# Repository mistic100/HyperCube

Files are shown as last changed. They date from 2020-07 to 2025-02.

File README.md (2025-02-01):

# HyperCube

Homemade clone of the [HyperCube by the Hyperspace Lighting Company](https://www.hyperspacelight.com/the-hypercube). 23cm wide.

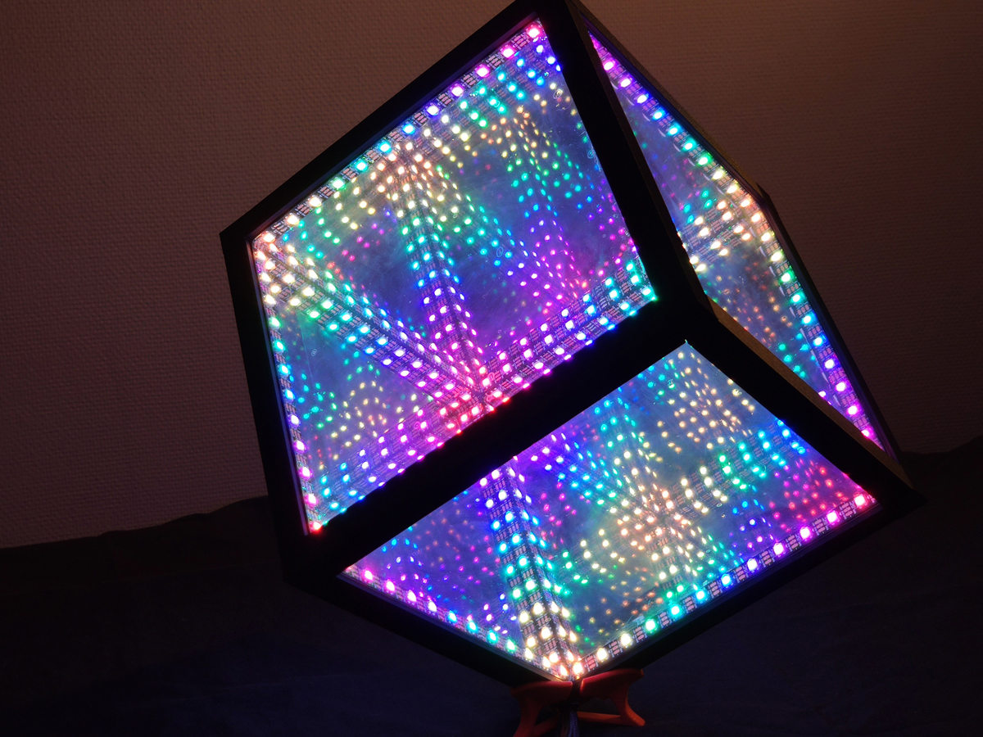
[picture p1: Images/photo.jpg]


[Photos on my website](https://galerie.strangeplanet.fr/index.php?/category/199)

## Parts list

### 3D printed parts

- 6x beam
- 2x beam-w-hole
- 2x beam-bottom (one symmetry !)
- 2x beam-bottom-w-hole (one symmetry !)
- 4x corner
- 4x corner-bottom
- 5x corner-cache
- 1x corner-cache-w-hole
- 4x panel-holder
- 1x electronics-case-support
	- use the alt version if you don't want to include a push-button

### Hardware

- 6x 210mm/2mm square one-way mirrors (or standard glass/PMAA with one-way film)
- 24x M2 15mm conical screws

### Electronics

- 6x 80cm WS2812 LED strips (60 LEDS/m)
- 1x Wemos D1 mini
- 1x 16mm push button
- 1x female DC jack with terminals
- 1x 5-10A 5V power supply

## Assembly

1. Start building the cube from the top panel, taking care where you use beams with or without holes to pass the wires. You will use all beams and corner pieces and five panels, dont put the last bottom panel yet
2. Cut the LED strips to length en solder the wires, I recommend using dedicated power lines for each strip but you can use a single wire for the data line
3. Glue the strips to each side and pass the wires in the beams, all wires must output on the same corner. I recommend adding CA glue as the standard 3M tape is not adhesive enough
4. Check that every strip is working correctly
5. Put the bottom panel and secure it in place by glueing the four panel holders
6. Glue all height corner caches

The following diagram shows one way to arrange strips (flattened cube seen from top).  
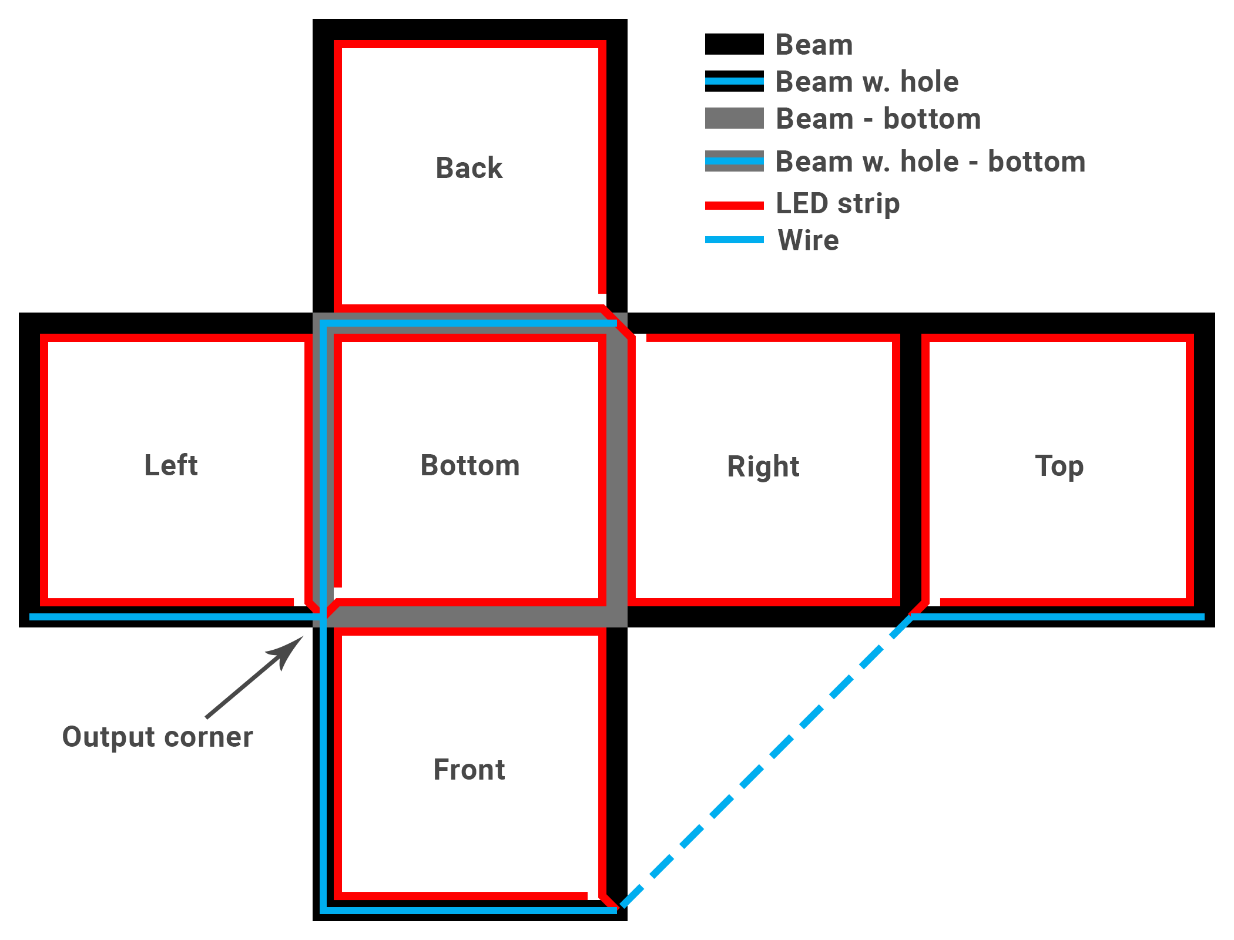
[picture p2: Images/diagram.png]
diagram


## Software

I recommend to install [WLED](https://kno.wled.ge/). Don't forget to divide the maximum power output by 6 as all the strips are in parallel.

However you can find in this repository a custom firmware I don't use anymore alongside a custom Android app. This was developped for an Arduino Nano with a Bluetooth module.

<details>
	<summary>Custom firmware and app</summary>

### Code

#### Configuration

Edit the `constants.h` file according to your wiring :

- `LED_PIN` output pin use to control LEDS
- `BUTTON_PIN` input pin for the control button
- `BLE_RXD` RX pin for the BLE module
- `BLE_TXD` TX pin for the BLE module

Edit `MAX_MILLI_AMPS` according to the rating of your power supply (keep a safety margin, especially with cheap Chinese stuff).

#### Controls

The cube is controlled via USB and Bluetooth and can received basic serial commands (`\n` terminated):

- `ON` to turn on the light
- `OFF` to turn off the light
- `BRIGHT X`(X=0-255) to change the brightness
- `BRIGHT+` to increase the brightness by 16
- `BRIGHT-` to decrease the brightness by 16
- `MODE X` to change the current mode, modes are:
	- `RAINBOW`
	- `RAINDROP`
	- `PULSE`
	- `CYLON`
	- `CHASER`
	- `NOISE`
	- `GRADIENT`
	- `RIPPLES`
- `MODE+` to use the next mode
- `MODE-` to use the previous mode
- `COLOR X` to change the current color, hues are:
	- `RAINBOW`
	- `RED`
	- `YELLOW`
	- `GREEN`
	- `BLUE`
	- `PINK`
	- `WHITE`
- `COLOR+` to use the next color
- `COLOR-` to use the previous color
- `SPEED X` (X=1-10) to change the speed
- `SPEED+` to increase the speed by 1
- `SPEED-` to decrease the speed by 1
- `PATTERN [A=X] [Z=X] C=X` use a custom color pattern
	- `A=X` (X=0/F/B): animate the pattern on `F`orward or `B`ackward direction (uses current `SPEED`)
	- `Z=X` (X=1-10): display the full pattern all at once or only a smaller portion
	- `C=X`: definition of up to 16 color stops, three character each, from `000` to `FFF`
	
*Note*: When controlled over Bluetooth, the controller must send a single `#` char and wait for the `OK` response before sending the command.
This is done to pause the FastLED processing and have enough CPU cycles to consume the larger request.

#### Examples of custom color pattern

- `C=f00`: All red
- `A=F C=000FFF`: Animated Black/White gradient
- `C=000FFF000FFF000FFF000FFF000FFF`: Static checker
- `A=B Z=5 C=F0000F`: Animated Red/Blue gradient with zoom applied
- `A=F Z=10 C=5F55F500000055F000`: Pulsating Green/Blue

*Note*: Commands over 20 chars long must be splitted into multiple packets, by limitation of the Serial over Bluetooth protocol.
Only the last packet will be `\n` terminated.

### Application

A flutter application (Android only) allows to control the light from your smartphone. It is only compatible with HM-10 Bluetooth modules.

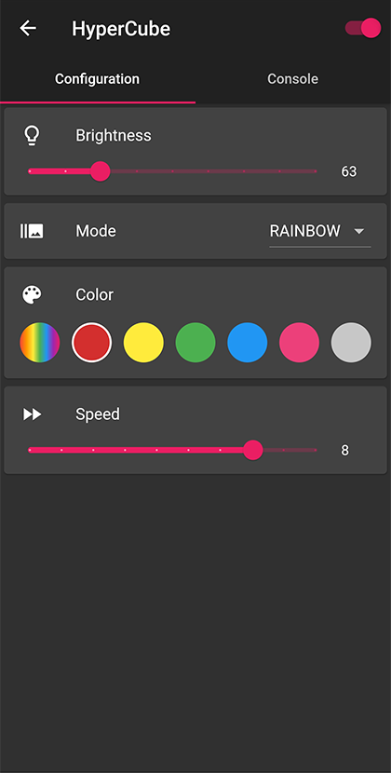
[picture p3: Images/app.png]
app
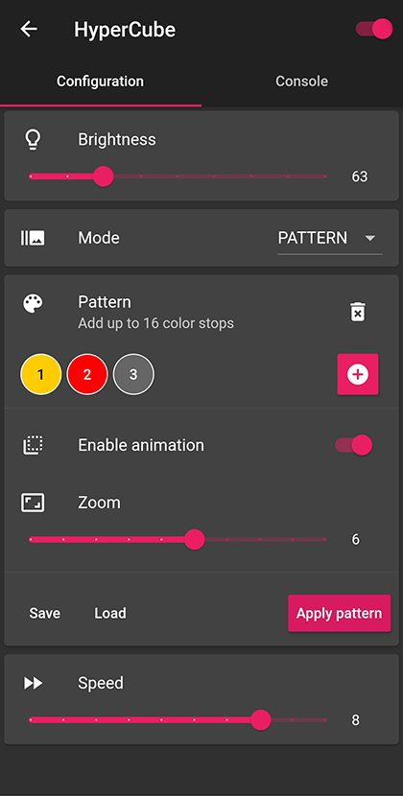
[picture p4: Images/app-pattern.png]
app-pattern
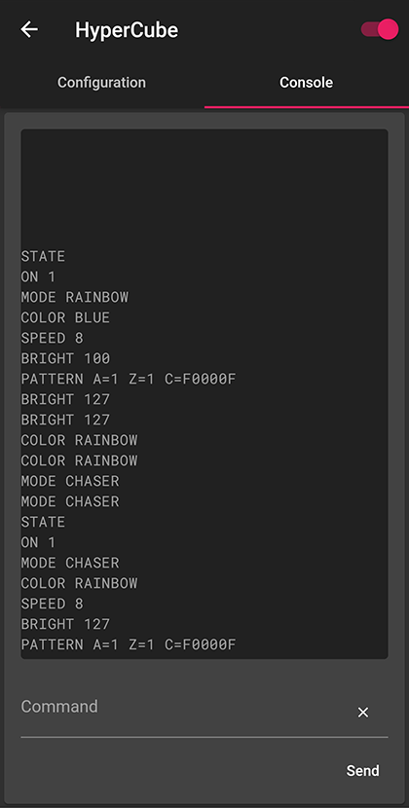
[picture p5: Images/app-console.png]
app-console
  

</details>

## License

The SolidWorks files, Arduino code and Flutter code are distributed under the Creative Commons 3.0 BY-SA license.

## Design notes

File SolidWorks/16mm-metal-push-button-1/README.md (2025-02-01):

https://grabcad.com/library/16mm-metal-push-button-1

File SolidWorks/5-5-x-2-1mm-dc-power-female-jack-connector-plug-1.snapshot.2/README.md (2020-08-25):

https://grabcad.com/library/5-5-x-2-1mm-dc-power-female-jack-connector-plug-1

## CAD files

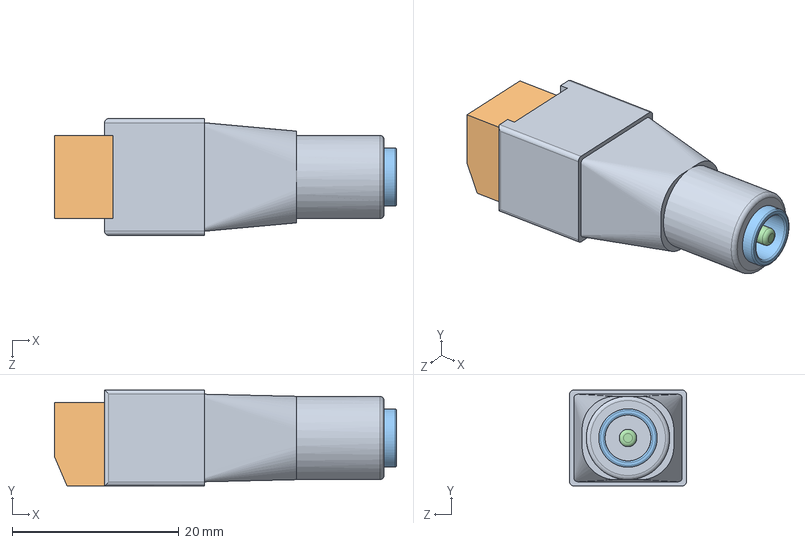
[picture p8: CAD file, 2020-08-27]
SolidWorks/5-5-x-2-1mm-dc-power-female-jack-connector-plug-1.snapshot.2/dc_power_jack_assembly.SLDASM
41.0 x 11.5 x 14.0 mm
main_body
green_screw_section
jack_outer_metal
jack_inner_rod
wireholder x 2

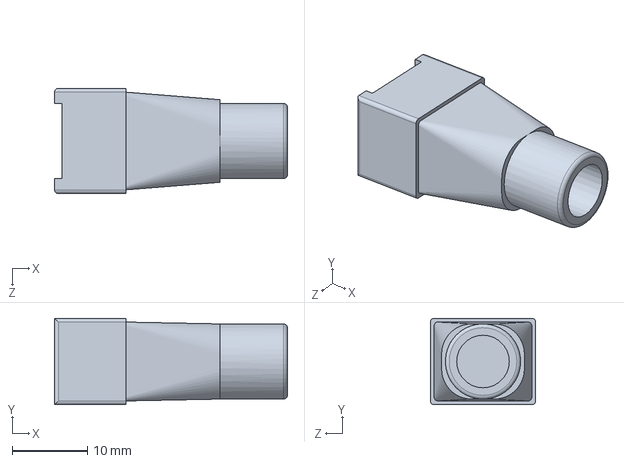
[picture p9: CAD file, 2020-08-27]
SolidWorks/5-5-x-2-1mm-dc-power-female-jack-connector-plug-1.snapshot.2/main_body.SLDPRT
31.0 x 11.5 x 14.0 mm

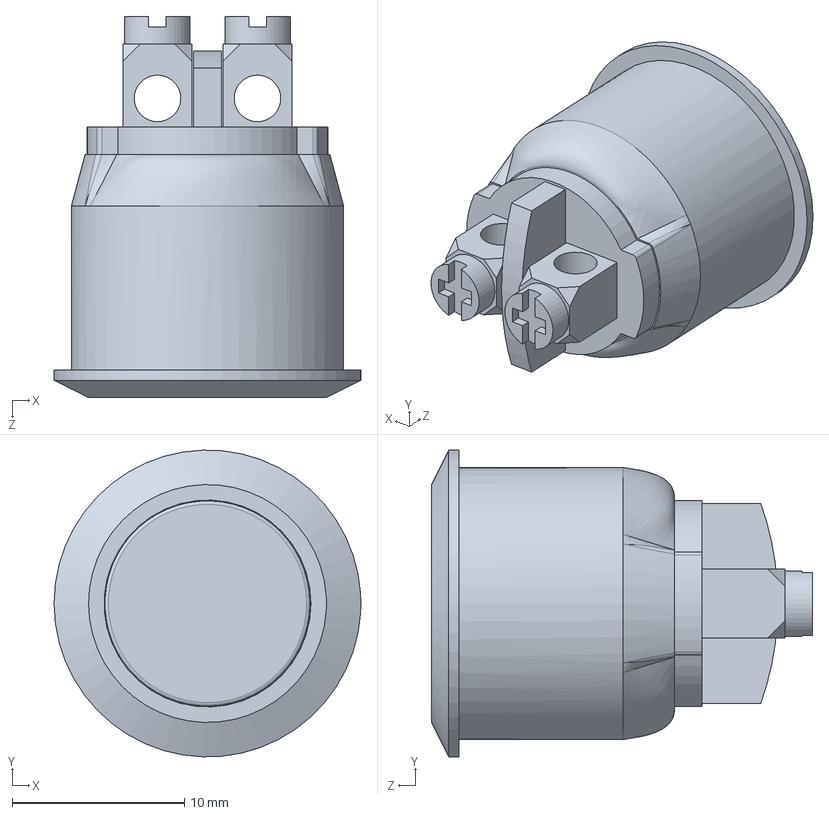
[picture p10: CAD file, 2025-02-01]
SolidWorks/16mm-metal-push-button-1/button.SLDPRT
17.8 x 17.8 x 22.1 mm

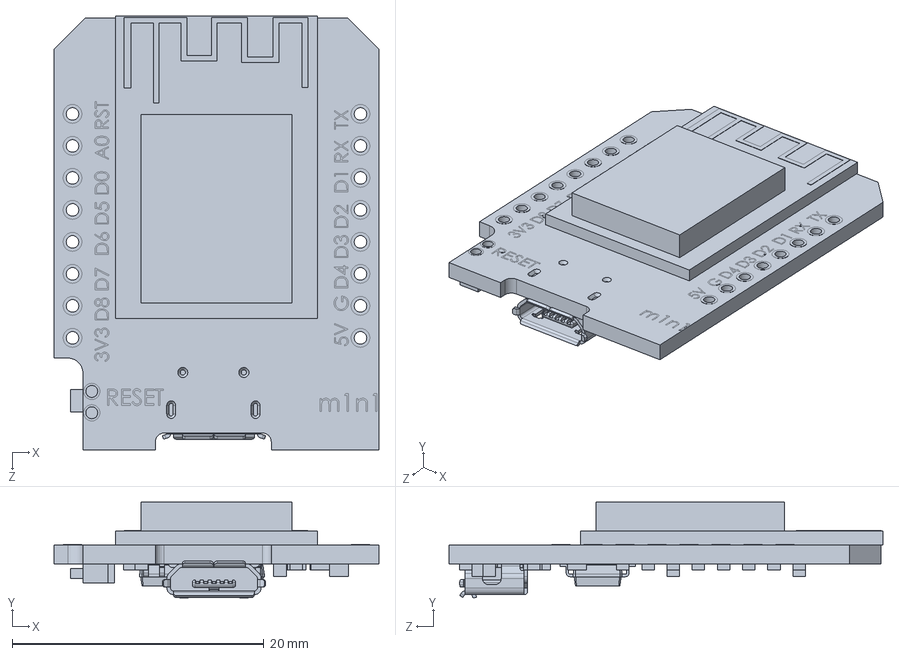
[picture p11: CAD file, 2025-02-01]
SolidWorks/wemos-d1-mini-more-accurate-version-1.snapshot.3/WEMOS-D1-mini_detailed.SLDPRT
25.8 x 7.60 x 34.4 mm

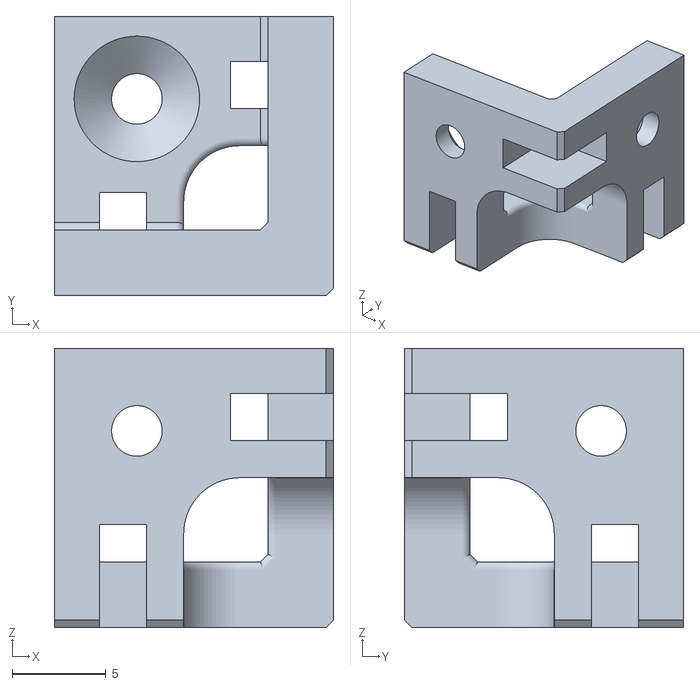
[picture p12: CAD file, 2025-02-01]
STL/corner (x4).STL
14.9 x 14.9 x 14.9

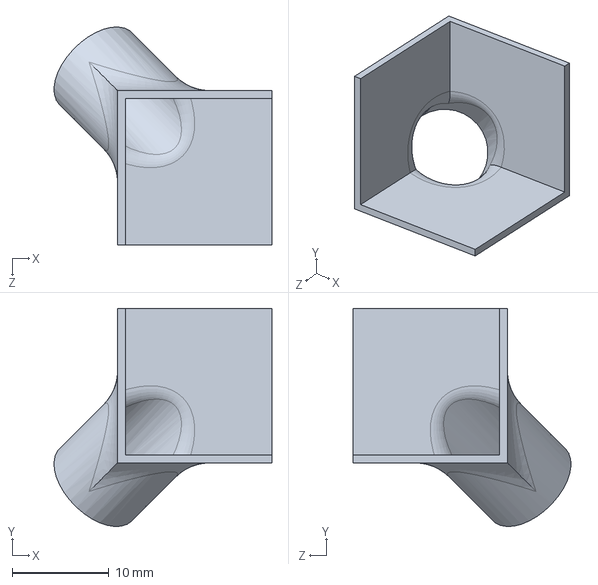
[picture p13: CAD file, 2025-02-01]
SolidWorks/corner-cache-w-hole.SLDPRT
22.6 x 22.6 x 22.6 mm

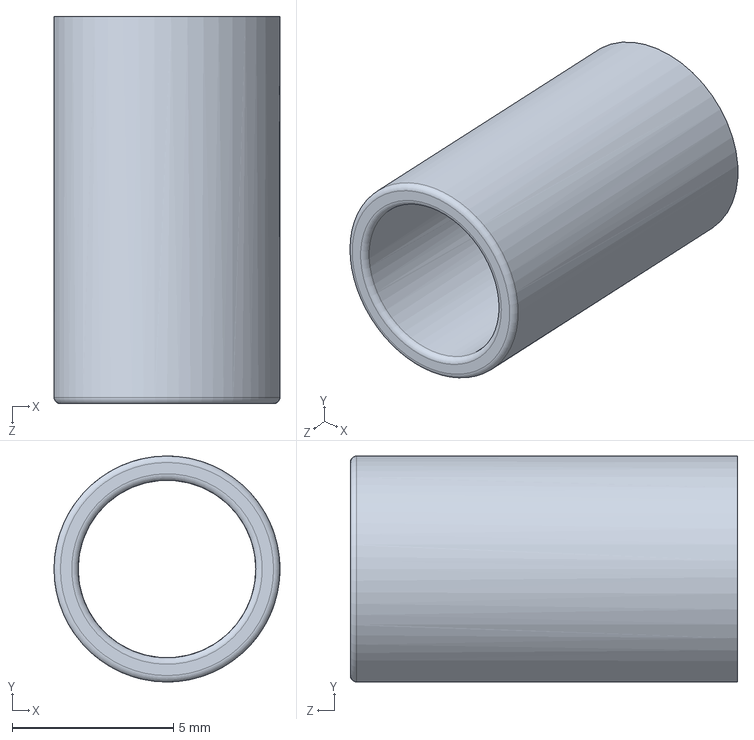
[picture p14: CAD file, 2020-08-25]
SolidWorks/5-5-x-2-1mm-dc-power-female-jack-connector-plug-1.snapshot.2/jack_outer_metal.SLDPRT
7.00 x 7.00 x 12.0 mm

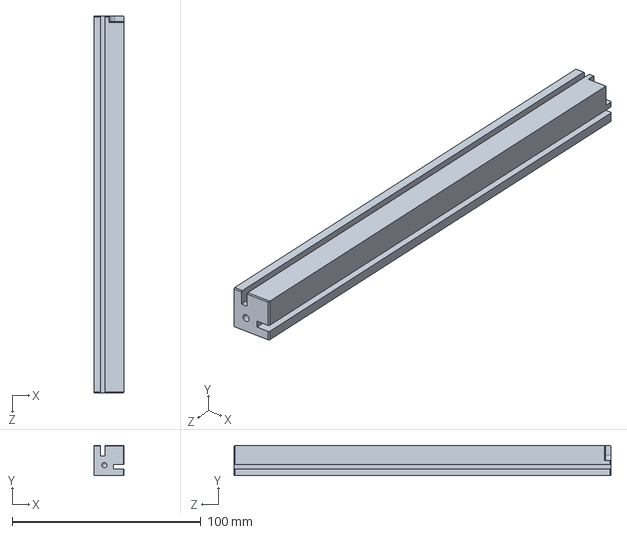
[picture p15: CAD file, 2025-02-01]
SolidWorks/beam.SLDPRT
16.0 x 16.0 x 200.0 mm

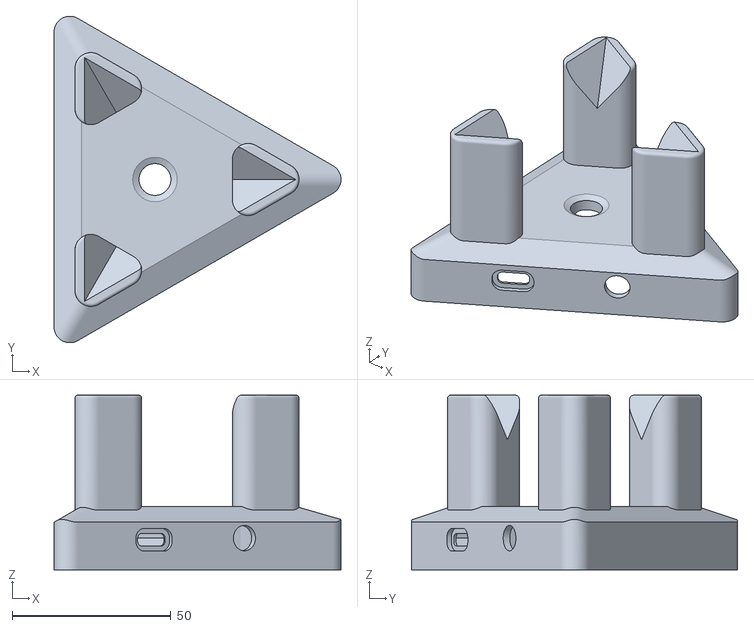
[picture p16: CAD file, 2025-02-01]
STL/electronics-case-support (alt) (x1).stl
90.3 x 102.7 x 55.0

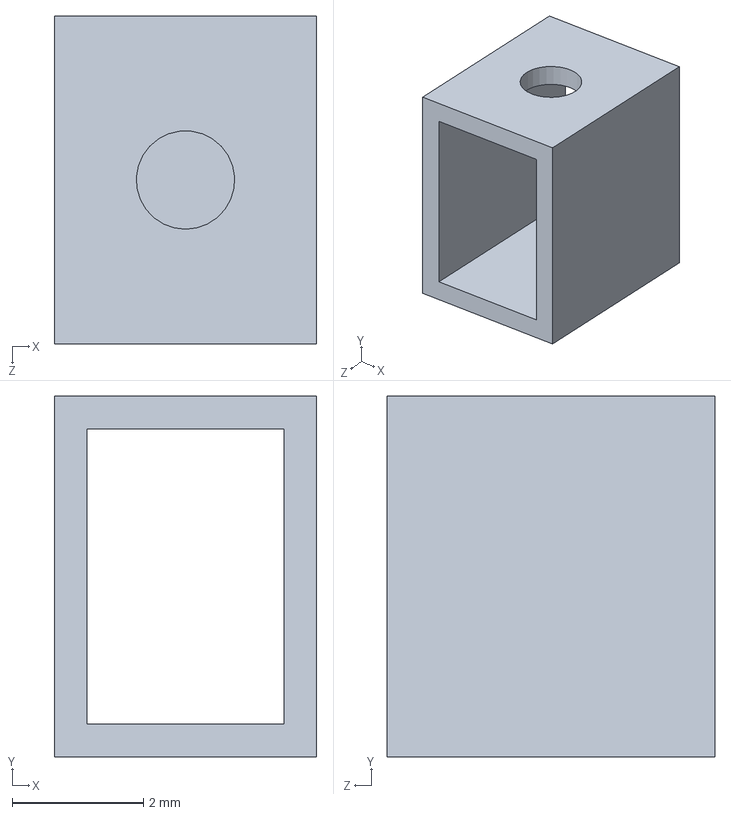
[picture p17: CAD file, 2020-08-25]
SolidWorks/5-5-x-2-1mm-dc-power-female-jack-connector-plug-1.snapshot.2/wireholder.SLDPRT
4.00 x 5.50 x 5.00 mm

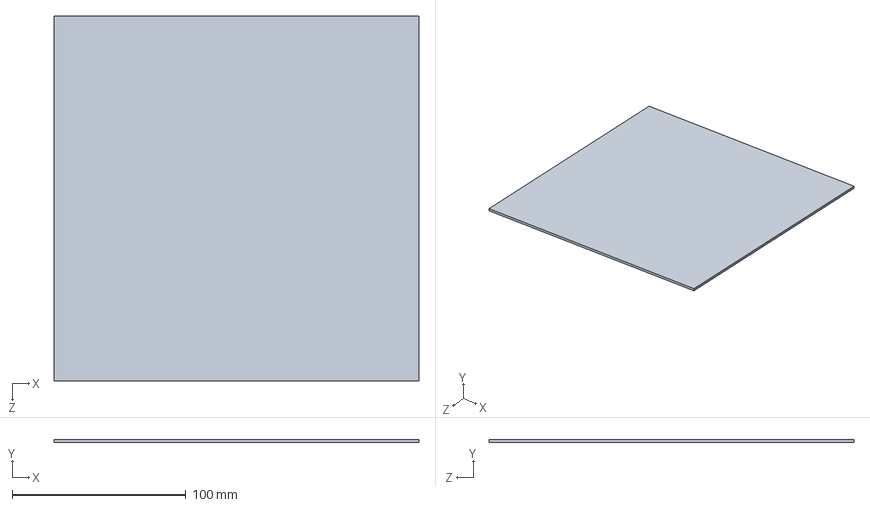
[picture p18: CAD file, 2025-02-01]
SolidWorks/glass.SLDPRT
210.0 x 2.00 x 210.0 mm

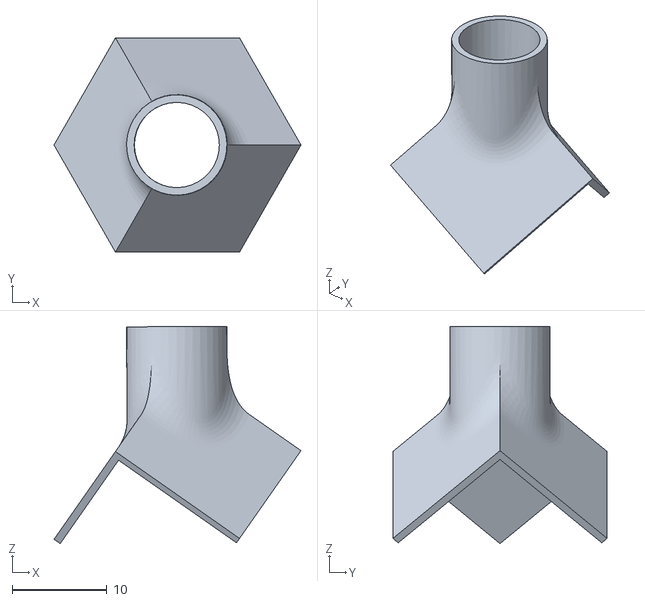
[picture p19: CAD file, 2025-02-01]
STL/corner-cache-w-hole (x1).STL
26.1 x 22.6 x 22.9

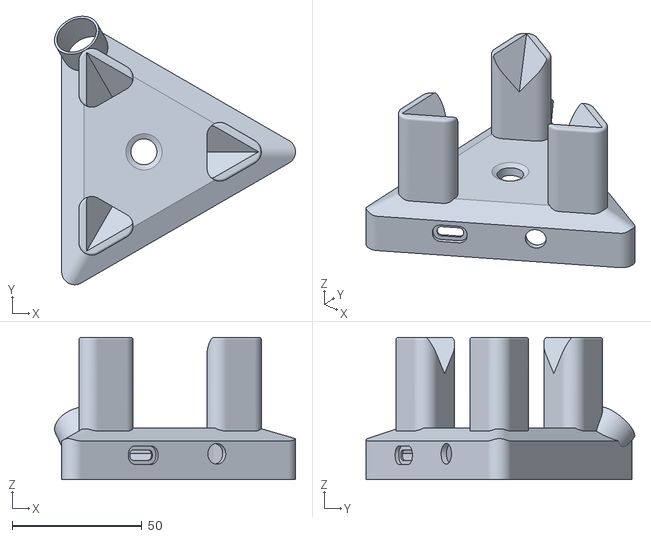
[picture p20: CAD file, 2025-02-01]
STL/electronics-case-support (x1).STL
93.0 x 103.7 x 55.0

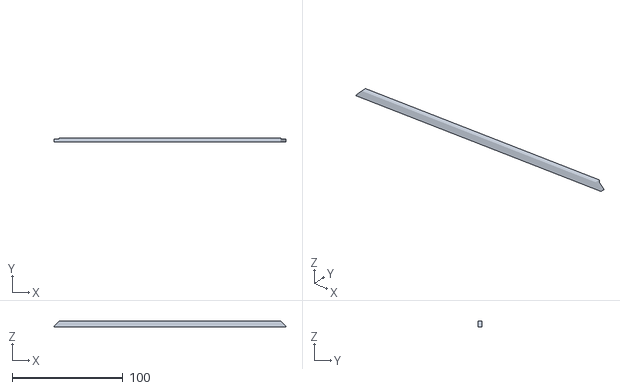
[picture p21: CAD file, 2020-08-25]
STL/panel-holder (x4).STL
209.1 x 4.00 x 5.50

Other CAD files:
SolidWorks/HyperCubeAndCase.SLDASM
SolidWorks/HyperCube.SLDASM
STL/corner-bottom (x4).STL
SolidWorks/electronics-case-support.SLDPRT
STL/beam (x6).STL
STL/beam-bottom (x1 + 1 symmetry).STL
STL/beam-bottom-w-hole (x1 + 1 symmetry).STL
STL/beam-w-hole (x2).STL
STL/corner-cache (x5).STL
SolidWorks/5-5-x-2-1mm-dc-power-female-jack-connector-plug-1.snapshot.2/green_screw_section.SLDPRT
SolidWorks/5-5-x-2-1mm-dc-power-female-jack-connector-plug-1.snapshot.2/jack_inner_rod.SLDPRT
SolidWorks/5-5-x-2-1mm-dc-power-female-jack-connector-plug-1.snapshot.2/wireholder_with_screw_assembly.SLDASM
SolidWorks/beam-base.SLDPRT
SolidWorks/beam-bottom-w-hole.SLDPRT
SolidWorks/beam-bottom-w-hole_symetry.SLDPRT
SolidWorks/beam-bottom.SLDPRT
SolidWorks/beam-bottom_symetry.SLDPRT
SolidWorks/beam-w-hole.SLDPRT
SolidWorks/corner-bottom.SLDPRT
SolidWorks/corner-cache.SLDPRT
SolidWorks/corner.SLDPRT
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

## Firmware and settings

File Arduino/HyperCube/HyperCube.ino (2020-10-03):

#include <FastLED.h>
#include <SoftwareSerial.h>
#include <CmdParser.hpp>
#include <AverageValue.h>
#include <EEPROM.h>
#include "constants.h"
#include "modes.h"
#include "colors.h"
#include "custom.h"
#include "Animations.h"

// animation manager
Animations *animations;

// Bluetooth serial
SoftwareSerial btSerial(BLE_RXD, BLE_TXD);

// Command parser
CmdParser cmdParser;
CmdBuffer<CMD_BUFFER_SIZE> cmdBuffer;

// pause LED processing
boolean pause = false;

// track if the EEPROM needs to be update
boolean needsSave = false;

// touch button value
AverageValue<long> buttonValue(40);
boolean buttonOff = false;

void setup() {
  pinMode(LED_BUILTIN, OUTPUT);
  
  animations = new Animations();

  uint8_t brightness = EEPROM.read(ADDR_BRIGHT);
  if (brightness == 0) {
    brightness = BRIGHTNESS_BASE;
  }
  uint8_t mode = EEPROM.read(ADDR_MODE);
  uint8_t color = EEPROM.read(ADDR_COLOR);
  uint8_t speed = EEPROM.read(ADDR_SPEED);
  if (speed == 0) {
    speed = SPEED_BASE;
  }

  if (EEPROM.read(ADDR_PATTERN) == CUSTOM_PATTERN_VERSION) {
    EEPROM.get(ADDR_PATTERN, animations->pattern);
  }

  animations->setBrightness(brightness);
  animations->setColor(Colors(color % NUM_COLORS));
  animations->setSpeed(speed);
  animations->setMode(Modes(mode == M_PATTERN ? mode : mode % NUM_MODES));

  Serial.begin(9600);
  btSerial.begin(BLE_BAUD);

  FastLED.addLeds<LED_TYPE, LED_PIN, COLOR_ORDER>(animations->leds, NUM_LEDS).setCorrection(TypicalLEDStrip);
  FastLED.setMaxPowerInVoltsAndMilliamps(5, MAX_MILLI_AMPS);
}

void loop() {
  if (!pause) {
    if (btSerial.available() && btSerial.read() == BLE_CTRL_CHAR) {
      // force empty the serial buffer
      delay(100);
      while (btSerial.available()) btSerial.read();
      
      pause = true;
      cmdBuffer.clear();
      btSerial.println(F("OK"));
    } else {
      processCommand(&Serial);
    }
  } else {
    if (processCommand(&btSerial)) {
      pause = false;
    }
  }
  
  EVERY_N_MILLIS_I(timer, 10) {
    buttonValue.push(analogRead(BUTTON_PIN));
    boolean newButtonOff = buttonValue.average() <= BUTTON_THRES;
    if (newButtonOff != buttonOff) {
      buttonOff = newButtonOff;
      if (buttonOff) {
        animations->off();
      } else {
        animations->on();
      }
    }

    if (!pause) {
      timer.setPeriod(animations->period);
      animations->run();
    
      FastLED.setBrightness(animations->brightness);
      FastLED.show();
    
      digitalWrite(LED_BUILTIN, animations->isOff ? LOW : HIGH);
    }
  }

  EVERY_N_SECONDS(5) {
    if (!pause) {
      printOn(&btSerial);
    }
    
    if (needsSave) {
      EEPROM.update(ADDR_BRIGHT, animations->brightness);
      EEPROM.update(ADDR_MODE, animations->mode);
      EEPROM.update(ADDR_COLOR, animations->color);
      EEPROM.update(ADDR_SPEED, animations->speed);
      EEPROM.put(ADDR_PATTERN, animations->pattern);
      needsSave = false;
    }
  }
}

boolean processCommand(Stream* serial) {
  // don't use CmdBuffer#readFromSerial which expects to receive the whole command at once
  bool done = false;
  while (serial->available()) {
      if (cmdBuffer.readSerialChar(serial)) {
          done = true;
          break;
      }
  }

  if (done) {
    cmdParser.setOptKeyValue(true);
    
    if (cmdParser.parseCmd(cmdBuffer.getBuffer(), cmdBuffer.getBufferSize()) != CMDPARSER_ERROR) {
      if (cmdParser.equalCommand_P(PSTR("ON"))) {
        animations->on();
        printOn(serial);
      }
      else if (cmdParser.equalCommand_P(PSTR("OFF"))) {
        animations->off();
        printOn(serial);
      }
      else if (cmdParser.equalCommand_P(PSTR("BRIGHT"))) {
        animations->setBrightness(atoi(cmdParser.getCmdParam(1)));
        needsSave = true;
        printBright(serial);
      }
      else if (cmdParser.equalCommand_P(PSTR("BRIGHT+"))) {
       animations->setBrightness(qadd8(animations->brightness, BRIGHTNESS_STEP));
        needsSave = true;
        printBright(serial);
      }
      else if (cmdParser.equalCommand_P(PSTR("BRIGHT-"))) {
        animations->setBrightness(qsub8(animations->brightness, BRIGHTNESS_STEP));
        needsSave = true;
        printBright(serial);
      }
      else if (cmdParser.equalCommand_P(PSTR("MODE"))) {
        animations->setMode(getMode(cmdParser.getCmdParam(1)));
        needsSave = true;
        printMode(serial);
      }
      else if (cmdParser.equalCommand_P(PSTR("MODE+"))) {
        animations->setMode(Modes((animations->mode + 1) % NUM_MODES));
        needsSave = true;
        printMode(serial);
      }
      else if (cmdParser.equalCommand_P(PSTR("MODE-"))) {
        animations->setMode(Modes(animations->mode == 0 ? NUM_MODES - 1 : animations->mode - 1));
        needsSave = true;
        printMode(serial);
      }
      else if (cmdParser.equalCommand_P(PSTR("COLOR"))) {
        animations->setColor(getColor(cmdParser.getCmdParam(1)));
        needsSave = true;
        printColor(serial);
      }
      else if (cmdParser.equalCommand_P(PSTR("COLOR+"))) {
        animations->setColor(Colors((animations->color + 1) % NUM_COLORS));
        needsSave = true;
        printColor(serial);
      }
      else if (cmdParser.equalCommand_P(PSTR("COLOR-"))) {
        animations->setColor(Colors(animations->color == 0 ? NUM_COLORS - 1 : animations->color - 1));
        needsSave = true;
        printColor(serial);
      }
      else if (cmdParser.equalCommand_P(PSTR("SPEED"))) {
        animations->setSpeed(atof(cmdParser.getCmdParam(1)));
        needsSave = true;
        printSpeed(serial);
      }
      else if (cmdParser.equalCommand_P(PSTR("SPEED+"))) {
        animations->setSpeed(qadd8(animations->speed, SPEED_STEP));
        needsSave = true;
        printSpeed(serial);
      }
      else if (cmdParser.equalCommand_P(PSTR("SPEED+"))) {
        animations->setSpeed(qsub8(animations->speed, SPEED_STEP));
        needsSave = true;
        printSpeed(serial);
      }
      else if (cmdParser.equalCommand_P(PSTR("PATTERN"))) {
        if (parseCustomPattern(&(animations->pattern),
            cmdParser.getValueFromKey_P(PSTR("C")),
            cmdParser.getValueFromKey_P(PSTR("A")),
            cmdParser.getValueFromKey_P(PSTR("Z"))) != CUSTOM_PATTERN_ERROR) {
          animations->setMode(M_PATTERN);
          needsSave = true;
          printPattern(serial);
        }
        else {
          serial->println(F("PATTERN_ERROR"));
        }
      }
      else if (cmdParser.equalCommand_P(PSTR("STATE"))) {
        printOn(serial);
        printBright(serial);
        printMode(serial);
        printColor(serial);
        printSpeed(serial);
        printPattern(serial);
      }
      else {
        serial->print(F("UNKNOWN_COMMAND "));
        serial->println((char*) cmdBuffer.getBuffer());
      }
    } else {
      serial->println(F("COMMAND_ERROR"));
    }
  }

  return done;
}

void printOn(Stream* serial) {
  serial->print(F("ON"));
  serial->print(F(" "));
  serial->println(animations->isOff ? F("0") : F("1"));
}

void printBright(Stream* serial) {
  serial->print(F("BRIGHT"));
  serial->print(F(" "));
  serial->println(animations->brightness);
}

void printMode(Stream* serial) {
  serial->print(F("MODE"));
  serial->print(F(" "));
  serial->println(getModeStr(animations->mode));
}

void printColor(Stream* serial) {
  serial->print(F("COLOR"));
  serial->print(F(" "));
  serial->println(getColorStr(animations->color));
}

void printSpeed(Stream* serial) {
  serial->print(F("SPEED"));
  serial->print(F(" "));
  serial->println(animations->speed);
}

void printPattern(Stream* serial) {
  serial->print(F("PATTERN"));
  serial->print(F(" "));
  serial->println(getPatternStr(&animations->pattern));
}

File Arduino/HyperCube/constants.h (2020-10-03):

#pragma once

// LEDS config
#define NUM_LEDS_SIDE 12
#define NUM_LEDS 4 * NUM_LEDS_SIDE
#define LED_TYPE WS2812
#define COLOR_ORDER GRB
#define MAX_MILLI_AMPS 8000
#define LED_PIN 6

// Button config
#define BUTTON_PIN A0
#define BUTTON_THRES 2

// BLE config
#define BLE_RXD 2
#define BLE_TXD 3
#define BLE_BAUD 9600
#define BLE_CTRL_CHAR '#'

// EEPROM config
#define ADDR_BRIGHT 0
#define ADDR_MODE 1
#define ADDR_COLOR 2
#define ADDR_SPEED 3
#define ADDR_PATTERN 64

// Other config
#define BRIGHTNESS_STEP 16
#define BRIGHTNESS_BASE 127
#define SPEED_STEP 1
#define SPEED_BASE 8

// longest command "PATTERN A=1 Z=10 C=" + stops * 3
#define CMD_BUFFER_SIZE 19 + 16 * 3

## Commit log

2020-08-25 Final design
    [1x3 TH Vert 100mil.step, CapacitiveButton.SLDASM, HC_05 Blue Tooth Module.stp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]
2020-08-27 Tweak case
    [HyperCubeCase.SLDASM, dc_power_jack_assembly.SLDASM, electronics-case.SLDPRT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]
2020-09-05 Assembly details
2020-09-13 Speed control, noise animation
    [Animations.h, HyperCube.ino, constants.h]
2020-09-14 Fix speed setting, add console in app
    [Animations.h, HyperCube.ino, constants.h]
2021-12-25 New support
    [HyperCubeCaseSupport.SLDASM, WEMOS-D1-mini_detailed.SLDPRT, button (x1).STL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]
